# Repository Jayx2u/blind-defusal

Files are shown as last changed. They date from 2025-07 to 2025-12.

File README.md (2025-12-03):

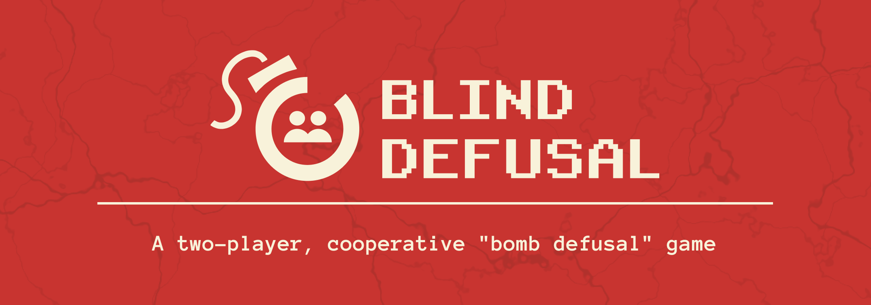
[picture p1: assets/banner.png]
Banner


# Blind Defusal - The Game
A two-player, cooperative "bomb defusal" game heavily inspired by "Keep Talking and Nobody Explodes"! One player is the `Operator` who has the physical device, and the other is the `Expert` who has the instruction manual but cannot see the device. Their goal is to disarm all the modules on the device before the timer runs out.

## How to Play
1. A person picks `Operator` and the other person picks the `Expert.` The `Operator` gets the bomb whilst the `Expert` gets the [manual](https://blind-defusal.jayx2u.fyi/). **Players are not allowed to look at each other's materials.**
2. The `Game Master` will set up the "Wire Pulling" module according to the instructions on the display located on the bomb when it is turned on. During this time the `Expert` is allowed to look over the manual but shall not communicate yet.
3. The `Game Master` will then start the game resulting in a five-minute timer starting. During this time, the players are allowed to communicate to each other only through verbal instructions and questions.

You either win by disarming the bomb by completing all the modules or losing by getting three strikes or making a fatal mistake - instantly detonating the bomb.

## Showcase
### Photos of the Hardware

Underside Photo
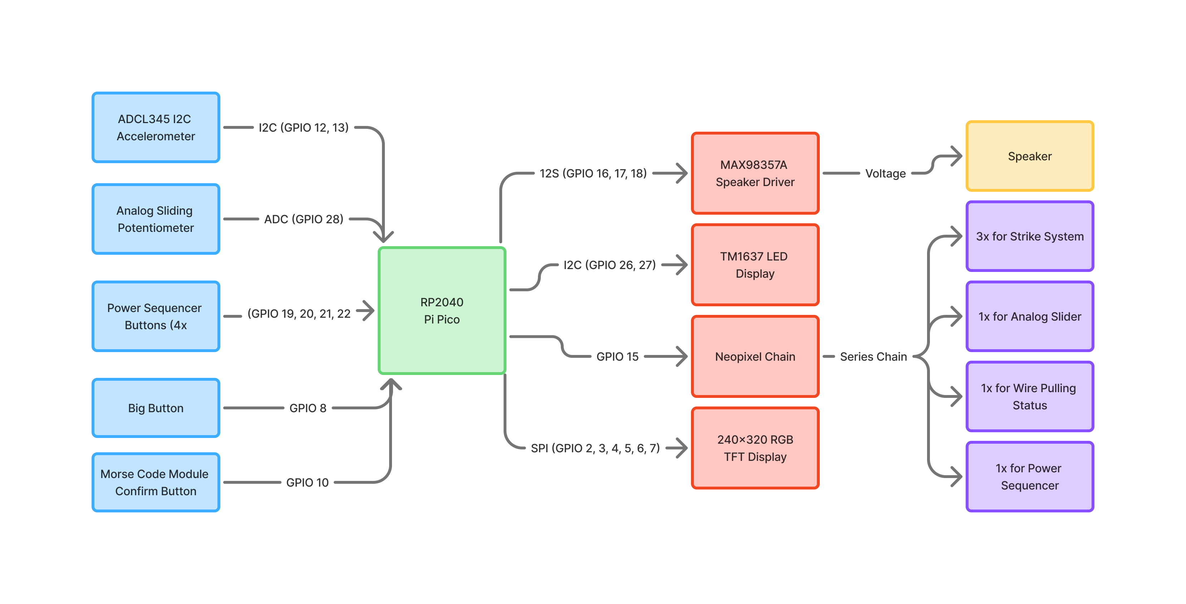
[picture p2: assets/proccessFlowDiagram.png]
Digram


### Video Demo
Video demo by [@Jayx2u](https://github.com/jayx2u) and [@pi-nf](https://github.com/pi-nf) available [here](https://youtu.be/Vhgq65tojBY)!

# Bill of Materials

<details>
<summary>Click to expand/collapse</summary>

| Item | Amount |
|---|---|
| Pico RP2040 | 1 |
| Xiao RP2040 | 1 |
| Breadboard | 5 |
| 1.28" TFT LCD | 1 |
| Neopixel | 4 |
| White LED | 1 |
| Switch | 1 |
| Button | 5 |
| Big A Button | 1 |
| IMU | 1 |
| Audio amplifier | 1 |
| Jumper wires | 64 |
| Potentiometer slider | 1 |
| 7 segment display | 1 |
| Speaker | 1 |
| 680ohm resistors | 1 |

</details>

<hr>

Made with ❤️ by [@ConfusedHello](https://github.com/confusedhello), [@Jayx2u](https://github.com/Jayx2u/) and [@pi-nf](https://github.com/pi-nf) during [Hack Club x Github Undercity 2025 @ GitHub HQ](https://undercity.hackclub.com/).

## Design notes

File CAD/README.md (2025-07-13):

# Blind Defusal Bomb Case
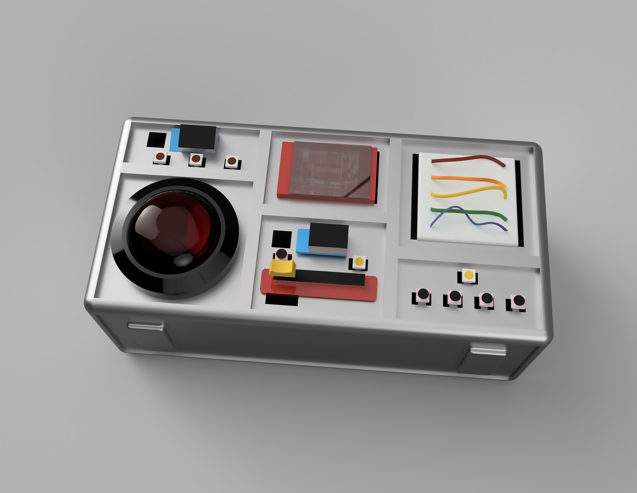
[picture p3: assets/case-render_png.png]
Render


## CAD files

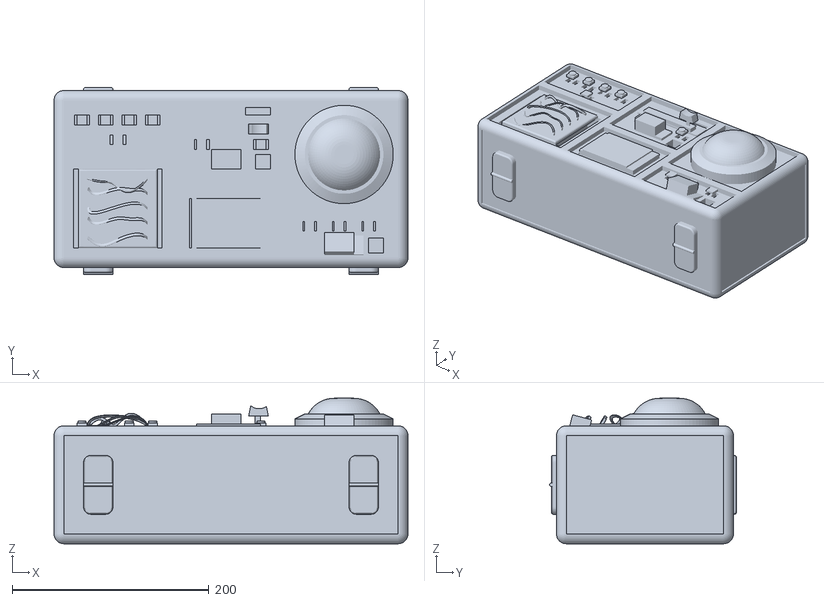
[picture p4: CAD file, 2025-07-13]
CAD/blind defusal modelV2.1PRINTING.stl
360.0 x 190.0 x 148.0

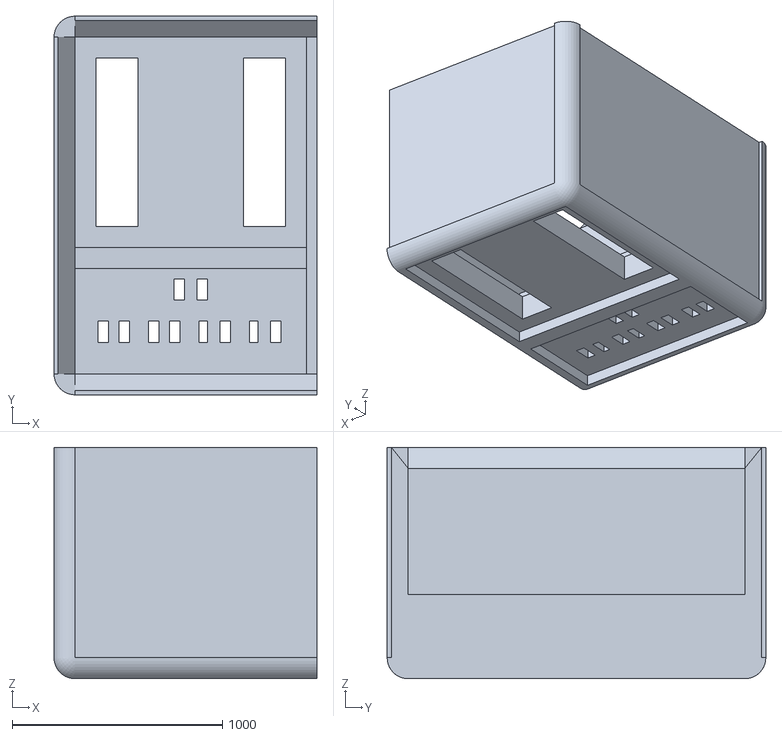
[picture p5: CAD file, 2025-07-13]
CAD/blind defusal PRINTINGTopRV3 for real this time.stl
1250.0 x 1800.0 x 1100.0

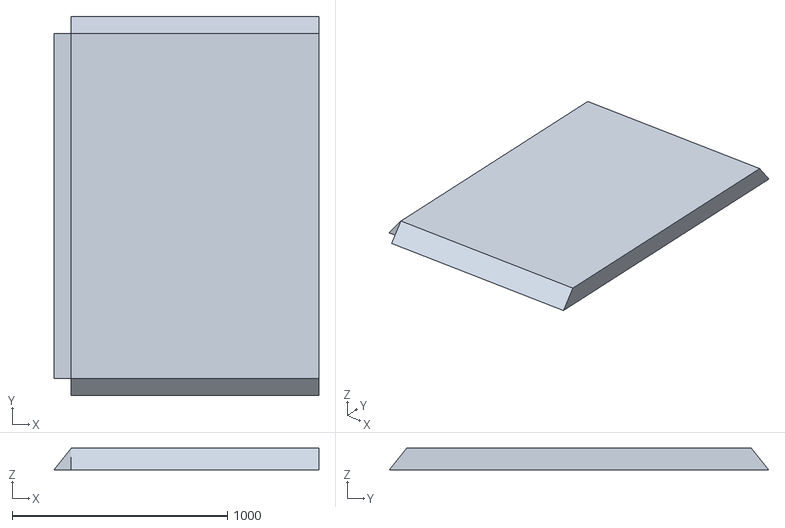
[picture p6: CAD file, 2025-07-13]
CAD/blind defusal PRINTINGBtmRV3 for real this time.stl
1230.0 x 1760.0 x 100.0

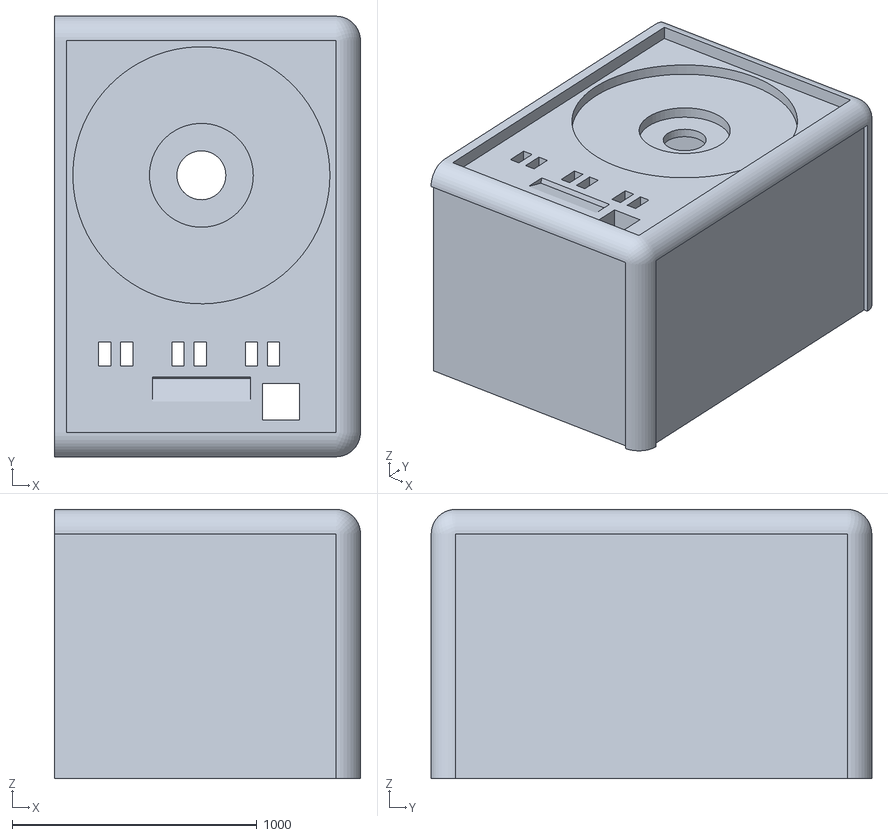
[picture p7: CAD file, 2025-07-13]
CAD/blind defusal PRINTINGTopLV3for real this time.stl
1250.0 x 1800.0 x 1100.0

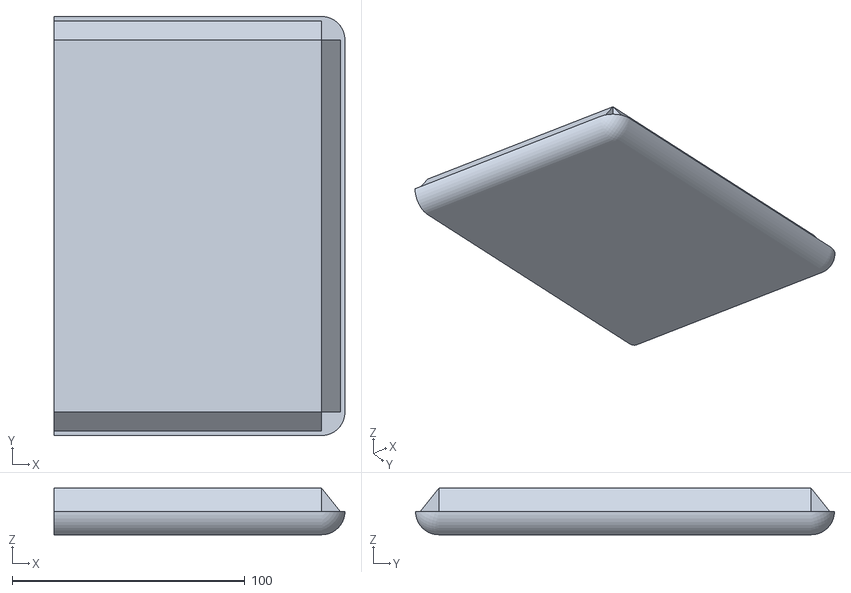
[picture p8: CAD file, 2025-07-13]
CAD/blind defusal PRINTINGBtmLV3 for real this time.stl
125.0 x 180.0 x 20.0

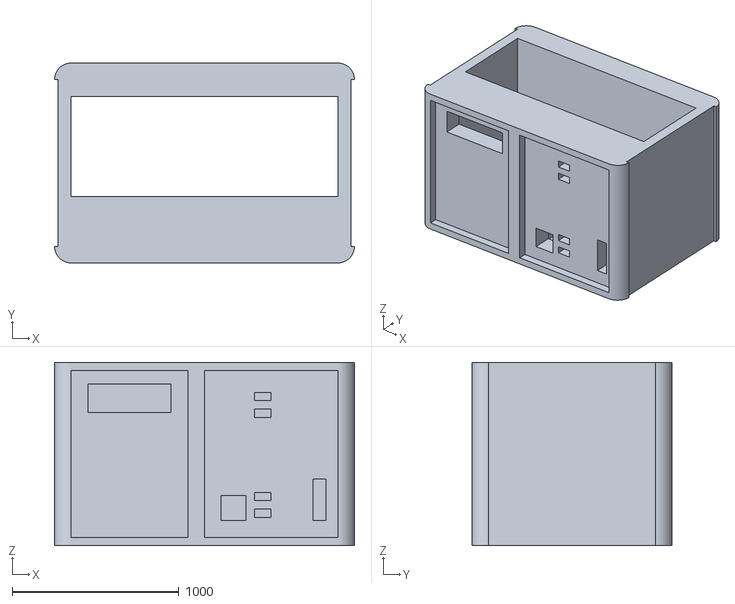
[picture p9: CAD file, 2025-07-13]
CAD/blind defusal PRINTINGMidV3 for real this time.stl
1800.0 x 1200.0 x 1100.0

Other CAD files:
CAD/blind defusal modelV2.1PRINTING.f3d

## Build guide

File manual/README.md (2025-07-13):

# Blind Defusal Manual
A web server with the Expert's manual made in Nextjs and hosted on Vercel.

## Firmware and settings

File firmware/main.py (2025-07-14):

import time
import board
import random
import neopixel
import audiocore
import audiobusio, displayio, busio

from adafruit_display_text import label
import terminalio

from analogio import AnalogIn
from fourwire import FourWire
from digitalio import DigitalInOut, Direction, Pull

from TM1637 import TM1637
from adafruit_st7789 import ST7789
from adafruit_adxl34x import ADXL345


# ---------------- Game Setup ----------------
countdown_time = 300
strikes = 0

# ---------------- Debug Modes ----------------
Debug = False
IgnoreBABRule = False

# ---------------- GPIO pins ----------------

# Display
DISPLAY2_SCK_PIN = board.GP2
DISPLAY2_MOSI_PIN = board.GP3
DISPLAY2_MISO_PIN = board.GP4
DISPLAY2_CS_PIN = board.GP5
DISPLAY2_RST_PIN = board.GP6
DISPLAY2_DC_PIN = board.GP7

DISPLAY1_DIO_PIN = board.GP26
DISPLAY1_CLK_PIN = board.GP27

# BAB Module
BIG_BUTTON_PIN = board.GP8
BIG_BUTTON_LED_PIN = board.GP0

# Gyro Needy Module
ACCELEROMETER_SDA_PIN = board.GP12
ACCELEROMETER_SCL_PIN = board.GP13

# RBG LEDs
NEOPIXEL_PIN = board.GP15

# Speakers
AUDIO_SCK_PIN = board.GP16
AUDIO_WS_PIN = board.GP17
AUDIO_SD_PIN = board.GP18

# Power Sequencer Module
SEQUENCER_BUTTON_PINS = [board.GP19, board.GP20, board.GP21, board.GP22]

# Morse Code Module
POTENTIOMETER_PIN = board.GP28
TRANSMIT_BUTTON_PIN = board.GP10


# ---------------- Helper Classes/Functions ----------------
last_pot_value = 0 # Last potentiometer value

class Potentiometer:
    def __init__(self, pin):
        self.adc = AnalogIn(pin)
        self.choices = [3505, 3515, 3522, 3532, 3535, 3542, 3545, 3552, 3555, 3565, 3572, 3575, 3582, 3592, 3595, 3600]

    @property
    def value(self):
        return 3600 - 0.95 * self.adc.value / 65535 * 100

    @property
    def snapped_value(self):
        return min(self.choices, key=lambda x: abs(x - self.value))


# Helper functions for serial number checks
def serial_has_vowel():
    return any(char in "AEIOU" for char in serial_number)


def serial_last_digit_is_even():
    # Find the last digit in the serial number
    last_digit = -1
    for char in serial_number:
        if char.isdigit():
            last_digit = int(char)

    if last_digit == -1:  # No digits in serial
        return False
    return last_digit % 2 == 0

def all_other_modules_solved():
    """Checks if all non-needy, non-BAB modules are solved."""
    return (morse_state == "SOLVED" and
            sequencer_state == "SOLVED")

# ---------------- Peripherals ----------------

# Timer display
display1 = TM1637(DISPLAY1_CLK_PIN, DISPLAY1_DIO_PIN)

# Audio output
audio_out = audiobusio.I2SOut(AUDIO_SCK_PIN, AUDIO_WS_PIN, AUDIO_SD_PIN)

# Accelerometer
accel_i2c = busio.I2C(
    ACCELEROMETER_SCL_PIN,
    ACCELEROMETER_SDA_PIN,
    frequency=400_000
)
accelerometer = ADXL345(accel_i2c)

# Potentiometer
potentiometer = Potentiometer(POTENTIOMETER_PIN)

# Buttons
big_button = DigitalInOut(BIG_BUTTON_PIN)
big_button.direction = Direction.INPUT
big_button.pull = Pull.UP

sequence_button1 = DigitalInOut(SEQUENCER_BUTTON_PINS[3])
sequence_button1.direction = Direction.INPUT
sequence_button1.pull = Pull.UP

sequence_button2 = DigitalInOut(SEQUENCER_BUTTON_PINS[2])
sequence_button2.direction = Direction.INPUT
sequence_button2.pull = Pull.UP

sequence_button3 = DigitalInOut(SEQUENCER_BUTTON_PINS[1])
sequence_button3.direction = Direction.INPUT
sequence_button3.pull = Pull.UP

sequence_button4 = DigitalInOut(SEQUENCER_BUTTON_PINS[0])
sequence_button4.direction = Direction.INPUT
sequence_button4.pull = Pull.UP

# Transmit Button (Morse Code Module)
transmit_button = DigitalInOut(TRANSMIT_BUTTON_PIN)
transmit_button.direction = Direction.INPUT
transmit_button.pull = Pull.UP

# Neopixels
neopixels = neopixel.NeoPixel(NEOPIXEL_PIN, 5, brightness=0.2)

# BAB LED
big_button_led = DigitalInOut(BIG_BUTTON_LED_PIN)
big_button_led.direction = Direction.OUTPUT

# TFT Display
displayio.release_displays()

spi = busio.SPI(
    clock=DISPLAY2_SCK_PIN,
    MOSI=DISPLAY2_MOSI_PIN
)

while not spi.try_lock():
    pass

spi.configure(baudrate=24_000_000)
spi.unlock()

display_bus = FourWire(spi,
    command=DISPLAY2_DC_PIN,
    chip_select=DISPLAY2_CS_PIN,
    reset=DISPLAY2_RST_PIN
)

display2 = ST7789(display_bus,
    width=320, height=240,
    rotation=90,
    rowstart=0, colstart=0,
    bgr=True, invert=False
)

# screen = displayio.Group()
screen = displayio.CIRCUITPYTHON_TERMINAL # For Debugging
display2.root_group = screen


# ---------------- Other Config ----------------
Alive = True
game_started = False
game_disarmed = False
Completed = [0, 0, 0, 0, 0]  # Tracks completion of each sequence

# --- IDENTIFICATION: Serial Number ---
possible_serial_numbers = ["SN48K2", "FRQ1A3"]
serial_number = random.choice(possible_serial_numbers)
chosen_serial_index = possible_serial_numbers.index(serial_number)
print(f"Serial Number: {serial_number}")

# --- IDENTIFICATION: Battery ---
num_batteries = random.randint(1, 4)
print(f"Batteries: {num_batteries}")

# Sounds
tick_sound = audiocore.WaveFile(open("/assets/tick.wav", "rb"))
explosion_sound = audiocore.WaveFile(open("/assets/explosion.wav", "rb"))

# Wire Pulling Module
WIRE_PULLING_PINS = [board.GP9, board.GP11, board.GP14, board.GP23, board.GP24, board.GP25]

COLORS = {
    "RED": (255, 0, 0),
    "YELLOW": (255, 255, 0),
    "GREEN": (0, 255, 0),
    "CYAN": (0, 255, 255),
    "BLUE": (0, 0, 255),
    "PURPLE": (180, 0, 255),
    "WHITE": (255, 255, 255),
    "BLACK": (1, 1, 1),  # Using a very dim white for "black"
    "OFF": (0, 0, 0)
}

color_sequences = [
    ["RED", "BLUE", "GREEN", "YELLOW"],
    ["YELLOW", "RED", "BLUE", "GREEN"],
    ["BLUE", "GREEN", "YELLOW", "RED"],
    ["GREEN", "YELLOW", "RED", "BLUE"],
    ["RED", "RED", "BLUE", "YELLOW"]
]

# Time and Gyro
last_second_tick = 0.0
last_accel_update = 0.0
last_acceleration = None
STRIKE_THRESHOLD = 15.0 # m/s^2, gravity is ~9.8. Adjust for sensitivity.

# Morse Code Module Config
MORSE_CODE = { 'A':'.-', 'B':'-...', 'C':'-.-.', 'D':'-..', 'E':'.',
               'F':'..-.', 'G':'--.', 'H':'....', 'I':'..', 'J':'.---',
               'K':'-.-', 'L':'.-..', 'M':'--', 'N':'-.', 'O':'---',
               'P':'.--.', 'Q':'--.-', 'R':'.-.', 'S':'...', 'T':'-',
               'U':'..-', 'V':'...-', 'W':'.--', 'X':'-..-', 'Y':'-.--',
               'Z':'--..'}
MORSE_WORDS = ["SHELL", "HALLS", "SLICK", "TRICK", "BOXES", "LEAKS", "STROBE",
               "BISTRO", "FLICK", "BOMBS", "BREAK", "BRICK", "STEAK", "STING",
               "VECTOR", "BEATS"]
MORSE_FREQUENCIES = {
    "SHELL": 3505, "HALLS": 3515, "SLICK": 3522, "TRICK": 3532,
    "BOXES": 3535, "LEAKS": 3542, "STROBE": 3545, "BISTRO": 3552,
    "FLICK": 3555, "BOMBS": 3565, "BREAK": 3572, "BRICK": 3575,
    "STEAK": 3582, "STING": 3592, "VECTOR": 3595, "BEATS": 3600
}

morse_correct_frequency = 0

# Morse Code Module State
morse_state = "IDLE"
morse_word_to_send = ""
morse_char_index = 0
morse_signal_index = 0
morse_last_time = 0.0
morse_time_unit = 0.5 # seconds for one dot

# Power Sequencer Module State
sequencer_state = "IDLE"  # IDLE, STARTING, SHOW_SEQUENCE, AWAIT_INPUT, SOLVED
sequencer_sequence = []
sequencer_correct_presses = []
sequencer_user_presses = []
sequencer_color_index = 0
sequencer_last_flash_time = 0.0
sequencer_flash_interval = 0.75 # seconds

# Wire Pulling Buttons
wire_buttons = []
for pin in WIRE_PULLING_PINS:
    button = DigitalInOut(pin)
    button.direction = Direction.INPUT
    button.pull = Pull.UP
    wire_buttons.append(button)

# Wire Pulling Module State
wire_pulling_state = "STARTING" # STARTING, AWAIT_INPUT, SOLVED, FAILED
wire_pulling_wires = []
wire_pulling_correct_wire_index = -1 # 0-based index

# Wire Pulling Setup Logic
if wire_pulling_state == "STARTING":
    num_wires = random.randint(3, 6)
    wire_colors = ["RED", "BLUE", "YELLOW", "WHITE", "BLACK"]
    wire_pulling_wires = [random.choice(wire_colors) for _ in range(num_wires)]

    # Determine correct wire to pull based on rules
    # Note: Wire indices are 1-based in rules, 0-based in code.
    if num_wires == 3:
        if "RED" not in wire_pulling_wires:
            wire_pulling_correct_wire_index = 1 # Second wire
        elif wire_pulling_wires[-1] == "WHITE":
            wire_pulling_correct_wire_index = 2 # Last wire
        elif wire_pulling_wires.count("BLUE") > 1:
            # Find index of last blue wire
            wire_pulling_correct_wire_index = len(wire_pulling_wires) - 1 - wire_pulling_wires[::-1].index("BLUE")
        else:
            wire_pulling_correct_wire_index = 2 # Last wire
    elif num_wires == 4:
        if wire_pulling_wires.count("RED") > 1 and not serial_last_digit_is_even():
            wire_pulling_correct_wire_index = len(wire_pulling_wires) - 1 - wire_pulling_wires[::-1].index("RED")
        elif wire_pulling_wires[-1] == "YELLOW" and "RED" not in wire_pulling_wires:
            wire_pulling_correct_wire_index = 0 # First wire
        elif wire_pulling_wires.count("BLUE") == 1:
            wire_pulling_correct_wire_index = 0 # First wire
        else:
            wire_pulling_correct_wire_index = 1 # Second wire
    elif num_wires == 5:
        if wire_pulling_wires[-1] == "BLACK" and not serial_last_digit_is_even():
            wire_pulling_correct_wire_index = 3 # Fourth wire
        elif wire_pulling_wires.count("RED") == 1 and wire_pulling_wires.count("YELLOW") > 1:
            wire_pulling_correct_wire_index = 0 # First wire
        elif "BLACK" not in wire_pulling_wires:
            wire_pulling_correct_wire_index = 1 # Second wire
        else:
            wire_pulling_correct_wire_index = 0 # First wire
    elif num_wires == 6:
        if "YELLOW" not in wire_pulling_wires and not serial_last_digit_is_even():
            wire_pulling_correct_wire_index = 2 # Third wire
        elif wire_pulling_wires.count("YELLOW") == 1 and wire_pulling_wires.count("WHITE") > 1:
            wire_pulling_correct_wire_index = 3 # Fourth wire
        elif "RED" not in wire_pulling_wires:
            wire_pulling_correct_wire_index = 5 # Last wire
        else:
            wire_pulling_correct_wire_index = 3 # Fourth wire

    wire_pulling_state = "AWAIT_INPUT"
    print(f"Wires: {wire_pulling_wires}")
    print(f"Correct Wire: {wire_pulling_correct_wire_index + 1}")

# Big Ass Button Module State
bab_state = "STARTING"  # STARTING, AWAIT_INPUT, HELD, SOLVED
bab_led_is_on = False
bab_correct_action = "" # "PRESS" or "HOLD"
bab_hold_strip_color = "" # "BLUE", "YELLOW", "OTHER"
bab_release_digit = -1

# Big Ass Button Setup Logic
if bab_state == "STARTING":
    # Randomize bomb features for this module
    bab_led_is_on = random.choice([True, False])
    big_button_led.value = bab_led_is_on

    # Determine correct action based on rules
    if bab_led_is_on and num_batteries > 2:
        bab_correct_action = "PRESS"
    elif not bab_led_is_on and num_batteries > 1:
        bab_correct_action = "HOLD"
    elif bab_led_is_on and serial_has_vowel():
        bab_correct_action = "PRESS"
    else:
        bab_correct_action = "HOLD"

    # If holding, determine release rule
    if bab_correct_action == "HOLD":
        # Randomize the color of the "big display" for the release cue
        hold_color_choice = random.choice(["BLUE", "YELLOW", "WHITE", "GREEN", "RED"]) # Using a sample for "OTHER"
        if hold_color_choice == "BLUE":
            bab_hold_strip_color = "BLUE"
            bab_release_digit = 4
        elif hold_color_choice == "YELLOW":
            bab_hold_strip_color = "YELLOW"
            bab_release_digit = 5
        else:
            bab_hold_strip_color = hold_color_choice # Any other color
            bab_release_digit = 1

    bab_state = "AWAIT_INPUT"
    print(f"BAB Batteries: {num_batteries}, LED On: {bab_led_is_on}")
    print(f"BAB Action: {bab_correct_action}, Release Color: {bab_hold_strip_color}, Release Digit: {bab_release_digit}")

# Display and logging settings
pot_check_interval = 0.2  # seconds
last_pot_check_time = 0.0
pot_text_label = None
wire_text_label = None

# Create the display group first
screen = displayio.Group()

# Disarmed Display Group
disarm_screen = displayio.Group()
disarm_label = label.Label(
    terminalio.FONT, text="DISARMED", color=COLORS["GREEN"], scale=5,
    anchor_point=(0.5, 0.5), anchored_position=(display2.width // 2, display2.height // 2)
)
disarm_screen.append(disarm_label)

# Explosion Display Group
explosion_screen = displayio.Group()
explosion_label = label.Label(
    terminalio.FONT, text="YOU DIE :c", color=COLORS["RED"], scale=5,
    anchor_point=(0.5, 0.5), anchored_position=(display2.width // 2, display2.height // 2)
)
explosion_screen.append(explosion_label)


# Serial Number Label (always on)
serial_display_text = serial_number
if Debug:
    serial_display_text = f"Serial {chosen_serial_index + 1}"

serial_label = label.Label(
    terminalio.FONT, text=serial_display_text, color=0xFFFFFF, scale=2,
    anchor_point=(0.0, 0.0), anchored_position=(5, 5)
)
screen.append(serial_label)

# Battery Count Label (always on)
battery_display_text = f"{num_batteries} BATTERIES"
battery_label = label.Label(
    terminalio.FONT, text=battery_display_text, color=0xFFFFFF, scale=2,
    anchor_point=(0.0, 0.0), anchored_position=(5, 35)
)
screen.append(battery_label)


if Debug:
    # In debug mode, we will show the terminal on the display
    # Note: The labels added above will not be visible if the terminal takes over.
    screen = displayio.CIRCUITPYTHON_TERMINAL
else:
    # In normal mode, add the other module info labels
    # Potentiometer Frequency Label
    pot_text_label = label.Label(
        terminalio.FONT, text="", color=0xFFFF00, scale=2,
        anchor_point=(1.0, 0.0), anchored_position=(display2.width - 5, 5)
    )
    screen.append(pot_text_label)

    # Wire Pulling Module Label
    # wire_info_text = f"{len(wire_pulling_wires)} Wires: " + " ".join(w[0] for w in wire_pulling_wires)
    # wire_text_label = label.Label(
    #     terminalio.FONT, text=wire_info_text, color=0x00FFFF, scale=2,
    #     anchor_point=(0.5, 1.0), anchored_position=(display2.width // 2, display2.height - 10)
    # )
    #screen.append(wire_text_label)

    # Logo Label
    logo_info_text = "Blind Defusal"
    logo_text_label = label.Label(
        terminalio.FONT, text=logo_info_text, color=0x00FFFF, scale=2,
        anchor_point=(0.5, 1.0), anchored_position=(display2.width // 2, display2.height - 10)
    )
    screen.append(logo_text_label)

display2.root_group = screen


if Debug:
    # In debug mode, we will show the terminal on the display
    # Note: The labels added above will not be visible if the terminal takes over.
    screen = displayio.CIRCUITPYTHON_TERMINAL
else:
    # In normal mode, add the other module info labels
    # Potentiometer Frequency Label
    pot_text_label = label.Label(
        terminalio.FONT, text="", color=0xFFFF00, scale=2,
        anchor_point=(1.0, 0.0), anchored_position=(display2.width - 5, 5)
    )
    screen.append(pot_text_label)

    # Wire Pulling Module Label
    # wire_info_text = f"{len(wire_pulling_wires)} Wires: " + " ".join(w[0] for w in wire_pulling_wires)
    # wire_text_label = label.Label(
    #     terminalio.FONT, text=wire_info_text, color=0x00FFFF, scale=2,
    #     anchor_point=(0.5, 1.0), anchored_position=(display2.width // 2, display2.height - 10)
    # )
    # screen.append(wire_text_label)

display2.root_group = screen

# Reset Neopixels
neopixels[1] = COLORS["OFF"]
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

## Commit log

2025-07-12 Add initial case
    [blind-defusal-bomb-case.f3d]
2025-07-13 Add 3d print case files
    [blind defusal PRINTINGBtmLV3 for real this time.stl, blind defusal PRINTINGBtmRV3 for real this time.stl, blind defusal PRINTINGMidV3 for real this time.stl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]
2025-07-13 Full file with parts
    [blind defusal modelV2.1PRINTING.stl]
2025-07-13 full cad file with parts
    [blind defusal modelV2.1PRINTING.f3d]
2025-07-13 Change Gyro conditions
2025-07-13 Add case render
2025-07-14 Change incorrect condition in Power Sequencer
2025-07-14 firmware: Add power sequencer module and serial number gen
2025-07-14 firmware: Add wire pulling module and logic with new display settings
2025-07-14 manual: Change wire pulling module conditions
2025-07-14 firmware: Add battery ID and BAB module
2025-07-14 manual: Add battery identification
2025-07-14 firmware: Add initial start and add loop sequence to power sequencer
2025-07-14 firmware: Add game start system, correct orientation and enhance debugging
    [main.py]
2025-07-14 repo: Add BOM
2025-07-25 Add BOM to README
